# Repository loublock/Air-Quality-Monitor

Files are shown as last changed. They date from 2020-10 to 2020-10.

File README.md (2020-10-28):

# Air Quality Monitor

This project's topic is a device capable to measure the surrounding air quality dependent on CO2 and CO value as well as air temperature, pressure, and relative humidity. 
The idea is to monitor the air quality in order to give feedback on how "healthy" the air in your room really is. In times of Coronavirus, this can be used as an indicator to ventilate your office or living room in order to minimize the infection risk. A LED stripe signals you the time to ventilate the room and also when the CO2/CO concentration gets unhealthy.

## Table of Contents

1. Working principle
   1. Idea
   2. Sensors and actuators
   3. Code explanation
2. Adjustable parameters
3. Used hardware
4. Wiring
5. 3D printed housing
6. Assembly
7. Credits

## 1 Working principle
### 1.1 Idea
By measuring the gas concentration of CO2/CO the quality of the ambient air can be determined. Thinking of an office room for example, by having no other CO2 source than humans, the amount of CO2 in the air is relative to the number of people in the room and the time without ventilation. To minimize the risk of infection and maximize human performance, a small amount of CO2 is required. 

### 1.2 Sensors and actuators
The CO2/CO is measured by an MQ-135 gas sensor, returns the gas concentration in PPM (more in this repo: https://github.com/miguel5612/MQSensorsLib). This value depends on the temperature and the rel. humidity in the room. A BME280 sensor is used to get this information. Adding the temperature compensation to the MQSensorsLib according to formulas in this repo https://github.com/GeorgK/MQ135, we should get pretty accurate reading values. 

All the sensor values are shown on an I2C OLED display, switching between the two menus via a push button. If a critical value of CO2/CO in the room is reached, the indicator LEDs will blink red. They will scroll in orange when room ventilation is suggested. A gas concentration upper and lower limit is configured therefor.

### 1.3 Code explanation
In this section, I'll explain the most important functions in short. 

**loop()** is checking the gas limits, LED mode, and display mode. Pressing button one switches between the display modes, button two between the LED modes (gas warning and flashlight). The variables checked here get toggled in the button interrupt service routine (ISR).

**print_readings_display()** prints the regular three/four lines of reading values.

**print_alarm_value_display()** prints the gas reading value in big that exceeded it's upper limit.

**blink_LED()** blinking LEDs

**glow_LED()** LEDs on

**scroll_LED()** LEDs scrolling

**btn_press_ISR()** button ISR (debounced). Checks which button has been pressed and toggles the corresponding variable. (See more here: https://create.arduino.cc/projecthub/Svizel_pritula/10-buttons-using-1-interrupt-2bd1f8)

**init_mq135()** sets RL value according to define and reads out R0 from EEPROM.

**calibration_mq135()** calibrates the MQ135 R0 value if variable *mq135_cal_done* is set to false.

**get_mq135_readings()** reads sensor values, smoothes them and applies temperature/humidity compensation.

## 2 Adjustable parameters 

**Important: The MQ135 needs to be calibrated once! To do so change the variable *mq135_cal_done* on false and place it outside (fresh air). After heating (5 min) the calibration starts (30 sec). After that change the variable back to true, the calibrated R0 is written to EEPROM and is read out on device start.** 

- Resistor at pin B2 of your MQ135. (1k at most Chinese boards but it should one between 10k and 47k, 20k ideal.)

*#define RL 20* 

- Pre heating of MQ135 in milliseconds, 5 mins is recommended.

*#define HEATING_TIME 300000* 

- Your atmospheric CO2 value, if you know it exactly at your location.

*#define ATMOCO2 410* 

- Upper CO2 limit (when red blinking starts)

*#define CO2_MAX 2000* 

- Lower CO2 limit (when green glowing starts)
(Between upper and lower limit the LEDs scrolling in orange.)

*#define CO2_LOW 1000* 

- Upper CO limit (when red blinking starts)

*#define CO_MAX 70* 

- Lower CO limit (when green glowing starts)

*#define CO_LOW 40* 

You can change the pinout or anything else of course if you desire, but beware of side effects!

## 3 Used hardware 
- BME280 sensor board
- Oled I2C 128x32
- MQ-135 sensor board
- 2x push button
- WS2812 LED stripe 60 pixels/m
- Arduino Nano
- 20 mm round switch
- 6x M3x10 mm

## 4 Wiring 
*image coming soon*

**Arduino Nano:**

- **D7:** button 1
- **D6:** button 2 (or vise versa)
- **D2:** common button GND (same interrupt)
- **D5:** WS2812 LED stripe
- **A0:** MQ135
- **A4:** OLED + BME280 (I2C) SDA
- **A5:** OLED + BME280 (I2C) SCL

**BME280 (I2C):**

- **Vin:** +5V Arduino
- **GND:** GND Arduino
- **SCL:** A5 Arduino
- **SDA:** A4 Arduino

**Display (I2C):**

- **Vin:** +5V Arduino
- **GND:** GND Arduino
- **SCL:** A5 Arduino
- **SDA:** A4 Arduino

**MQ-135:**

- **Vin:** +5V Arduino
- **GND:** GND Arduino
- **A0:** A0 Arduino
- **D0:** Not connected

**Button 1:**

- **Vin:** D7 Arduino
- **GND:** D2 Arduino

**Button 2:**

- **Vin:** D6 Arduino
- **GND:** D2 Arduino

**LED stripe:**

- **Vin:** +5V Arduino
- **GND:** GND Arduino
- **Din:** D5 Arduino

## 5 3D printed housing
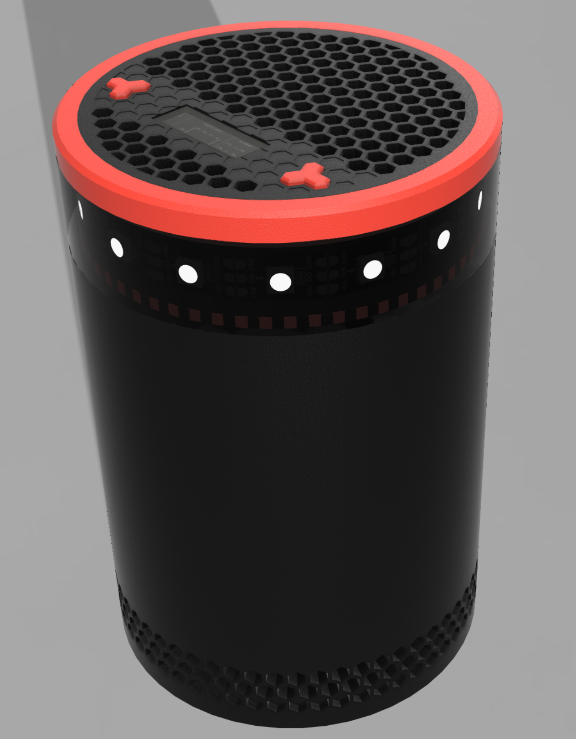
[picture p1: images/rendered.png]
rendered


Print all the files in the folder *3d_print* according to the table below. Please notice that you only need to print one lid, either the one with battery support or without. The one without battery is there to place your Arduino Nano in and connect it directly to USB power. The one with the battery support is able to hold up to four 18650 batteries as well as a charging board.

Part | Layer height | Color | Horizontal Expansion
---- | ------------ | ----- | --------------------
Top Grid | 0.2 mm | Black | -0.05 mm
Lower Housing | 0.2 mm | Black | 0
Button Bracket | 0.2 mm | Black | -0.05 mm
Sensor Bracket | 0.2 mm | Black | 0 
Button Left | 0.2 mm | Red | 0
Button Right | 0.2 mm | Red | 0
LED Mount | 0.2 mm | Red | -0.05 mm
Glass | 0.2 mm | Transparent | 0
Lid Battery | 0.2 mm | Black | 0 
Lid | 0.2 mm | Black | 0 

## 6 Assembly
Assemble all parts as shown in the picture and solder the cables concurrently. Screw the parts together with the M3's.

assembly

## 7 Credits

Thanks to **Matthias E.** for the design of the 3D-printed housing.

**MQ135 library:** Thanks to **Miguel A. Califa U.** (https://github.com/miguel5612/MQSensorsLib) for the general functions 
and **George K.** (https://github.com/GeorgK/MQ135) for the temperature compensation.

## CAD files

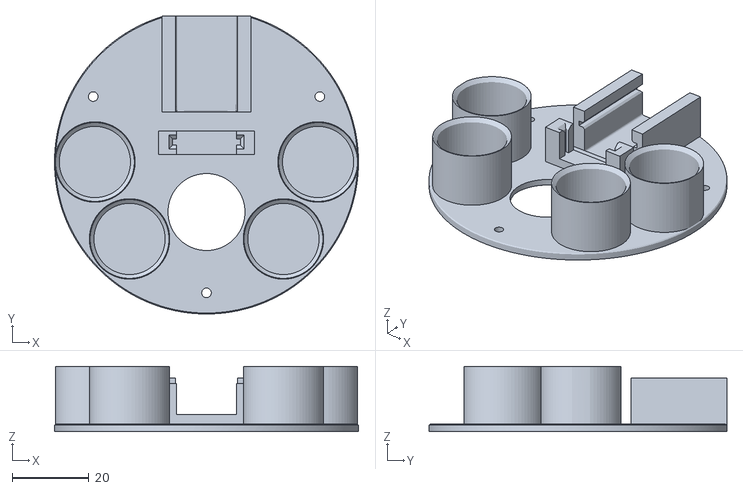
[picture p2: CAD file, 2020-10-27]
3d_print/black/lid_battery.stl
79.0 x 77.4 x 17.0

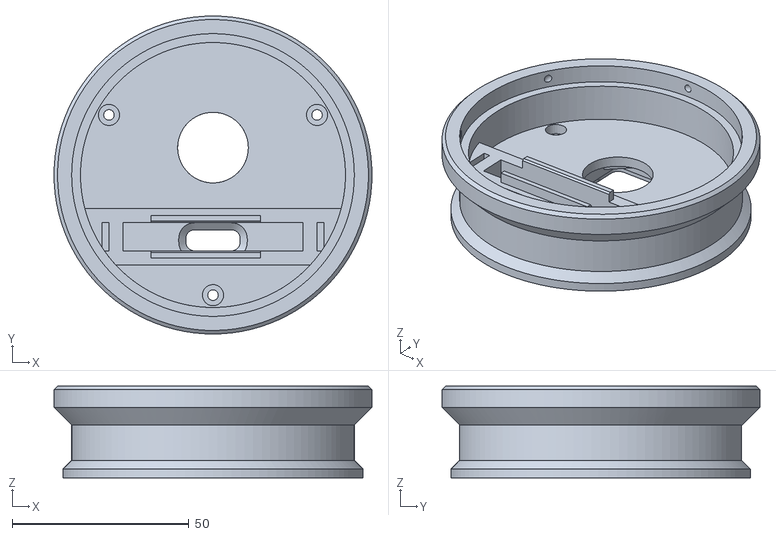
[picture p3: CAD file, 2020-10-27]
3d_print/red/led_mount.stl
90.0 x 90.0 x 26.0

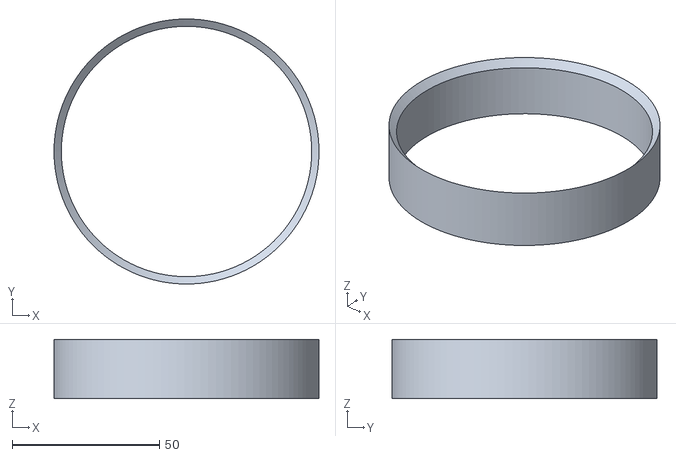
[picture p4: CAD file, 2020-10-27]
3d_print/transparent/glass.stl
90.0 x 90.0 x 20.1

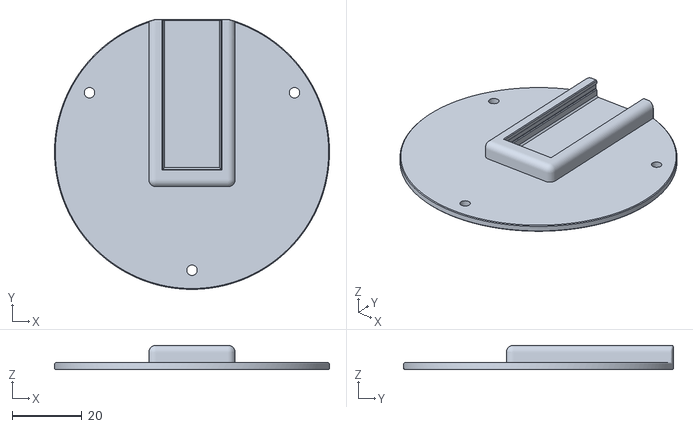
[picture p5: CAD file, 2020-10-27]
3d_print/black/lid.stl
79.0 x 77.5 x 7.00

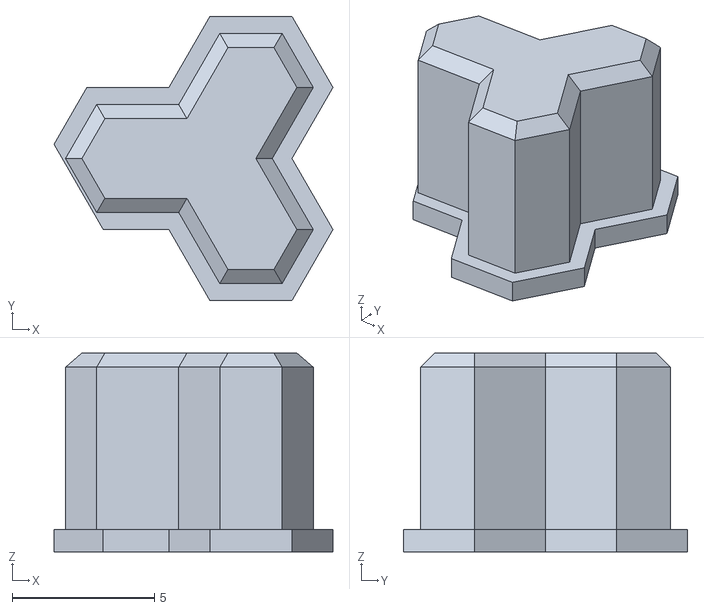
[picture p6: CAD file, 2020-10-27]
3d_print/red/button_left.stl
9.81 x 10.0 x 7.00

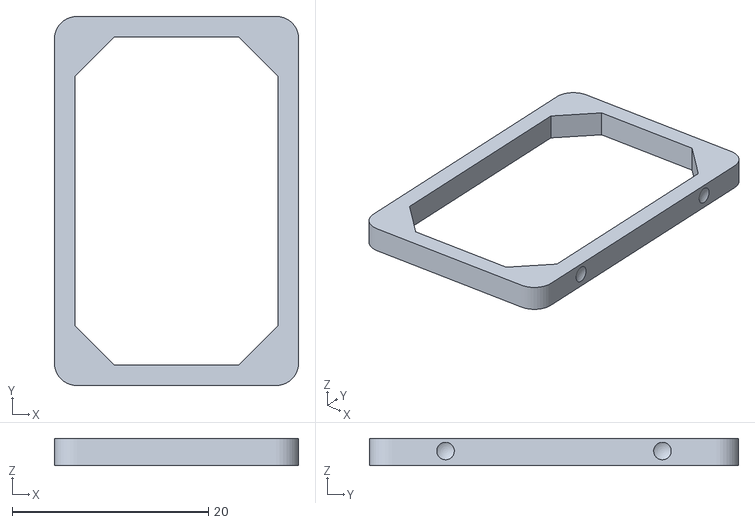
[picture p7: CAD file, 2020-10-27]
3d_print/black/sensor_bracket.stl
24.9 x 37.6 x 2.80

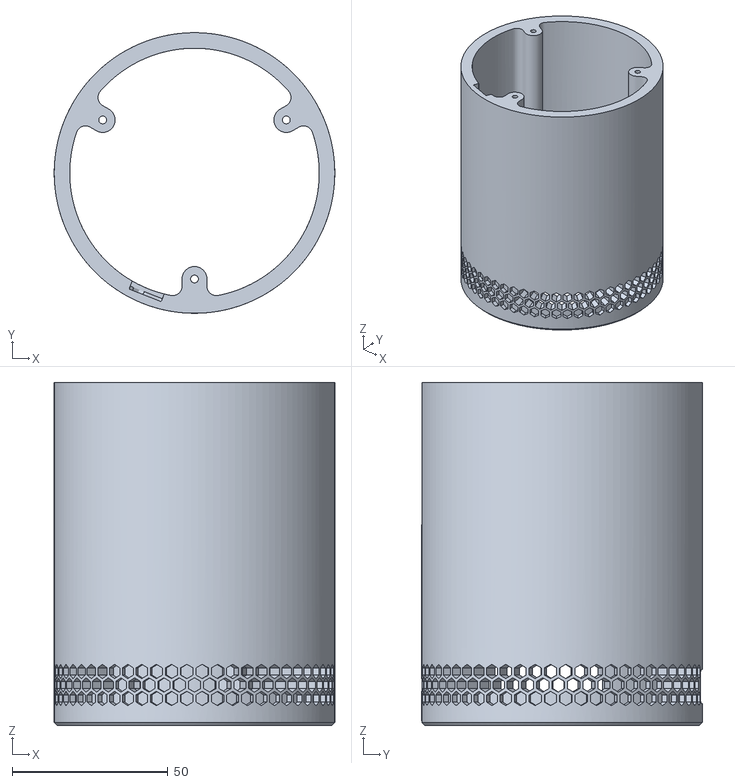
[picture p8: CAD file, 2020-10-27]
3d_print/black/lower_housing.stl
90.0 x 90.0 x 110.0

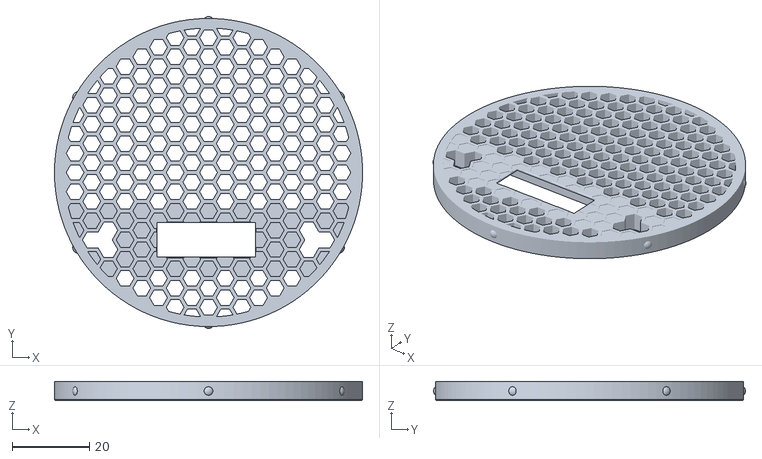
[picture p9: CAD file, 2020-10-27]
3d_print/black/top_grid.stl
80.0 x 81.0 x 5.00

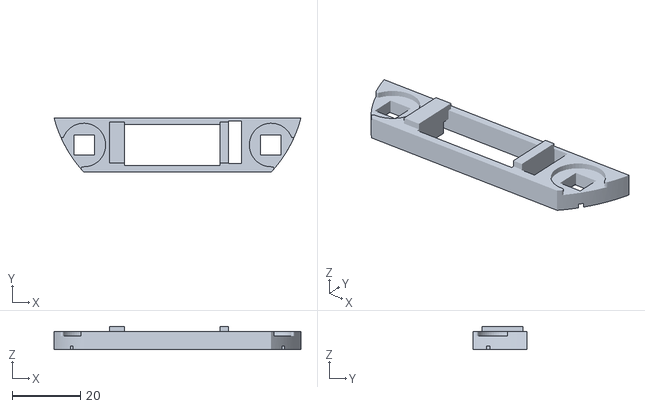
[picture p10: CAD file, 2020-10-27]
3d_print/black/button_bracket.stl
72.6 x 16.0 x 6.80

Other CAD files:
3d_print/red/button_right.stl

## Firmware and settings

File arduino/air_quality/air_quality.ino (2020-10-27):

// Created by Luis Garcia
// https://github.com/loublock 

/*
--------------- Quick Arduino Nano pinout ---------------
D7: button 1
D6: button 1 (or vise versa)
D2: common button GND (same interrupt)
D5: WS2812 LED stripe

A0: MQ135
A4: OLED + BME280 (I2C)
A4: OLED + BME280 (I2C)
*/

#include <SPI.h>
#include <Wire.h>
#include <Adafruit_BME280.h>
#include <Adafruit_GFX.h>
#include <Adafruit_SSD1306.h>
#include <Adafruit_NeoPixel.h>
#include "MQUnifiedsensor.h"
#include <EEPROM.h>

#define SCREEN_WIDTH 128 // OLED display width, in pixels
#define SCREEN_HEIGHT 32 // OLED display height, in pixels
// Declaration for an SSD1306 display connected to I2C (SDA, SCL pins)
#define OLED_RESET     -1 // Reset pin # (or -1 if sharing Arduino reset pin)

#define LED_PIN 5 // LED stripe on D5
#define NUM_LEDS 15 // amount of WS2812 LEDs on the stripe

// useful LED defines
#define FAST 200
#define MEDIUM 500
#define SLOW 1000

#define PIN_BTN_0 7 // button 1 on D7
#define PIN_BTN_1 6 // button 2 on D6
#define COMMON_BTN_PIN 2 // buttons GND on D2 (interrupt)

Adafruit_BME280 bme;

// MQ135 defines as seen in the examples of Miguel A. Califa U.
#define SEALEVELPRESSURE_HPA (1013.25)
#define RatioMQ135CleanAir 3.6

#define TYPE "MQ-135"
#define BOARD "Arduino Nano"
#define MQ_PIN A0 // MQ135 on A0
#define ADC_BIT_RES 10
#define VOLTAGE_RES 5
// Resistor Load on ground pin of MQ135
#define RL 20

// heating time in ms
#define HEATING_TIME 300000 //~ 5 min

// temperature and rel humidity correction according to Georg Krocker
#define CORA 0.00035
#define CORB 0.02718
#define CORC 1.39538
#define CORD 0.0018

// approx. atmospheric CO2 in ppm measured at Mauna Loa Observatory, Hawaii (NOAA)
// oct 2020
#define ATMOCO2 410

// gas limits - edit if neccessary
// in theory triggering on one gas should be fine bc the curves are related
#define CO2_MAX 2000
#define CO2_LOW 1000
#define CO_MAX 70
#define CO_LOW 40

// decl & init of sensor values
float humidity = 0.0;
float temperature = 0.0;
float pressure = 0.0;
float altitude = 0.0;
float co2 = 0.0;
float co = 0.0;
float nh4 = 0.0;
// float toluol = 0.0;

// scrolling index
unsigned int train_idx = 0;
unsigned int rainbow_count = 0;
//r0 of mq135
int calcR0 = 0; 

// set this to false to calibrate the MQ 135
bool mq135_cal_done = true;

Adafruit_SSD1306 display(SCREEN_WIDTH, SCREEN_HEIGHT, &Wire, OLED_RESET);
Adafruit_NeoPixel pixels = Adafruit_NeoPixel(NUM_LEDS, LED_PIN, NEO_GRB + NEO_KHZ800);
MQUnifiedsensor MQ135(BOARD, VOLTAGE_RES, ADC_BIT_RES, MQ_PIN, TYPE);

// init button state
bool btn0_state = HIGH;
bool btn1_state = HIGH;

// connect interrupt pins with routines
unsigned long last_fire = 0;

// ----triggers to set in ISR----
// 0: hum/temp/press 1: CO2/CO/NH4
bool display_mode = 0;
// 0: gas conc. color 1: lamp (white 255)
bool led_mode = 0;

// mq135 pre heating variables
bool heating = true;
float timer_heat = 0;

// smoothing the reading values
unsigned int n_smooth = 0;
const int smooth_limit = 10;
float co2_buffer[smooth_limit];
float co_buffer[smooth_limit];
float nh4_buffer[smooth_limit];
// float toluol_buffer[smooth_limit];




void setup() 
{
  Serial.begin(9600);

  configure_common();
  attachInterrupt(0, btn_press_ISR, FALLING);

  // SSD1306_SWITCHCAPVCC = generate display voltage from 3.3V internally
  if(!display.begin(SSD1306_SWITCHCAPVCC, 0x3C)) 
  { 
    // Serial.println(F("SSD1306 allocation failed"));
    for(;;); // Don't proceed, loop forever
  }

  init_timer();
  init_mq135();

  // oled init
  display.setRotation(2);
  display.setTextSize(1);      
  display.setTextColor(WHITE); 
  display.setCursor(0, 0);     
  display.cp437(true);         // Use full 256 char 'Code Page 437' font

  pixels.begin();

  // start BME sensor
  if (!bme.begin(0x76)) 
  {
    // Serial.println("Could not find a valid BME280 sensor, check wiring!");
    while (1);
  }

  // Clear the buffer
  display.clearDisplay();
  display.display();

  // setting up parameters
  display.setTextSize(2);
  display.setTextColor(WHITE);
  display.setCursor(0, 0);
  
  // Display static welcome text
  // \201 - ü \204 - ä \224 - ö \253 - ½
  display.println(F("Luft"));
  display.println(F("Qualit\204t"));
  display.display();

  delay(2000);

  display.clearDisplay();
  display.display();
}


void loop() 
{
  humidity = bme.readHumidity();
  temperature = bme.readTemperature(); 
  pressure = bme.readPressure() / 100.0F;
  altitude = bme.readAltitude(SEALEVELPRESSURE_HPA);

  // gets only executed when mq135_cal_done is initialized with false
  calibration_mq135();
  // get mq135 sensor values
  get_mq135_readings();

  // reset display or the display writes the new readings over the old ones
  display.display();
  display.clearDisplay();

  // wait for finishing heating
  if (timer_heat >= HEATING_TIME)
  {
    timer_heat = 0;
    heating = false;
//    Serial.println(F("Aufheizen abgeschlossen!"));
//    Serial.println(F("MQ135 betriebsbereit!"));
  }

  if (led_mode)
  {
    print_regular_readings();
    glow_LED('white', 255);
  }
  else if (!heating)
  {
    // co2: green: <=1000, orange: 2000>val>1500 red: >=2000
    // co: green: <=50, orange: 70>val>50 red: >=70
    if (co2 >= CO2_MAX || co >= CO_MAX)
    {
      // tehre's a bug: if you put the predefines color into the LED functions, the color is wrong.
      // Also if you put the dec/hex value as parameter. Only direct color set is working, so strings are given.
      blink_LED('red', FAST, 255);
      if (co2 >= CO2_MAX)
      {
        print_alarm_value_display("CO2: ", co2, "PPM", false, 0);
      }
      else
      {
        print_alarm_value_display("CO: ", co, "PPM", false, 0);
      }
    }
    else if (co2 <= CO2_LOW && co <= CO_LOW)
    {
      print_regular_readings();
      glow_LED('green', 15);
    }
    else
    {
      print_regular_readings();
      scroll_LED('orange', FAST, 5, 100);
    }
  }
  else
  {
    print_regular_readings();
    // rainbow_scroll_LED(); 
    scroll_LED('blue', MEDIUM, 5, 50);
  }
  

  // delay(10);
}


//----------------------OLED write routine---------------------------------------------------
void print_readings_display(float value, int line, String label, int offset, String unit, 
                            int textsize, bool is_spec_unit, int special_unit, bool blinking)
{
  display.setTextSize(textsize);
  display.setCursor(0, line);
  display.print(label);
  display.setCursor(offset, line);
  display.print(value);
  display.print(" ");

  if (is_spec_unit)
  {
    display.cp437(true);
    display.write(special_unit);
  }
 
  display.print(unit);
}


void print_alarm_value_display(String val_label, float alarm_value, String unit, 
                               bool is_spec_unit, int special_unit)
{
  // first print what value is alarming
  display.setTextSize(1);
  display.setCursor(0, 0);
  display.print(val_label);

  // then the value in big
  display.setTextSize(2);
  display.setCursor(0, 10);
  display.print(alarm_value);
  display.print(" ");

    if (is_spec_unit)
  {
    display.cp437(true);
    display.write(special_unit);
  }
 
  display.print(unit);
}


void print_regular_readings()
{
  if (!display_mode)
  {
    print_readings_display(co2, 0, "CO2: ", 40, "PPM", 1, false, 0, false);
    print_readings_display(co, 10, "CO: ", 40, "PPM", 1, false, 0, false);
    print_readings_display(nh4, 20, "NH4: ", 40, "PPM", 1, false, 0, false);
    // print_readings_display(toluol, 23, "Toluol: ", 40, "PPM", 1, false, 0, false);
    // print_readings_display(calcR0, 20, "R0: ", 40, "", 1, false, 0, false);
  }
  else
  {
    print_readings_display(temperature, 0, "Temperatur: ", 75, "C", 1, true, 167, false);
    print_readings_display(humidity, 7, "Feuchte: ", 75, "%", 1, false, 0, false);
    print_readings_display(pressure, 15, "Druck: ", 60, "hPa", 1, false, 0, false);
    print_readings_display(altitude, 23, "H\224he: ", 60, "m", 1, false, 0, false);
  }
}


//--------------------------LED stripe routines---------------------------------------------
void blink_LED(int color, int speed, int brightness)
// lets the LEDs blink in a specific color, brightness and speed
{
  pixels.setBrightness(brightness);
  pixels.show();

  // if off turn on
  if (pixels.getPixelColor(0) == pixels.Color(0,0,0))
  {
    for (int n=0; n<NUM_LEDS; n++)
    {
      // turn on the train pixels
      if (color == 'red')
        pixels.setPixelColor(n, pixels.Color(255,0,0));
      else if (color == 'green')
        pixels.setPixelColor(n, pixels.Color(0,255,0));
      else if (color == 'blue')
        pixels.setPixelColor(n, pixels.Color(0,0,255));
      else if (color == 'orange')
        pixels.setPixelColor(n, pixels.Color(255,165,0));
      else
        pixels.setPixelColor(n, pixels.Color(255,255,255));
    }
    
    pixels.show();
    }
  // else turn off
  else
  {
    pixels.clear();
    pixels.show();
  }
  
  delay(speed);
}


void glow_LED(int color, int brightness)
// just turn on the LEDs at specific color and brightness
{
  pixels.setBrightness(brightness);
  pixels.show();

  for (int n=0; n<NUM_LEDS; n++)
  {
    // turn on the train pixels
    if (color == 'red')
      pixels.setPixelColor(n, pixels.Color(255,0,0));
    else if (color == 'green')
      pixels.setPixelColor(n, pixels.Color(0,255,0));
    else if (color == 'blue')
      pixels.setPixelColor(n, pixels.Color(0,0,255));
    else if (color == 'orange')
      pixels.setPixelColor(n, pixels.Color(255,165,0));
    else
      pixels.setPixelColor(n, pixels.Color(255,255,255));
  }

  pixels.show();
}


void scroll_LED(int color, int speed, int length, int brightness)
// this function lets a specific amount of LEDs travel around the stripe
// at a specific speed
{
  int diff = 0;
  pixels.setBrightness(brightness);
  pixels.show();

  // create a - let's call it a train, a train of LED light pixels
  // it has a length of pixels and a speed with which it moves on the LED stripe
  for (int t=train_idx; t<train_idx+length; t++)
  {
    // turn on the train pixels
    if (color == 'red')
      pixels.setPixelColor(t, pixels.Color(255,0,0));
    else if (color == 'green')
      pixels.setPixelColor(t, pixels.Color(0,255,0));
    else if (color == 'blue')
      pixels.setPixelColor(t, pixels.Color(0,0,255));
    else if (color == 'orange')
      pixels.setPixelColor(t, pixels.Color(255,165,0));
    else
      pixels.setPixelColor(t, pixels.Color(255,255,255));
    
  }
  // make them gloooow
  pixels.show();

  // blinking speed is too slow for here
  delay(speed/10);

  pixels.clear();
  // pixels.show();  

  train_idx++;
  if ((train_idx + length) > NUM_LEDS)
  {
    train_idx = 0;
  }
}


void rainbow_scroll_LED()
{
  if (rainbow_count >= 65536)
  {
    rainbow_count = 0;
  }
  else
  {
    for(int i=0; i<NUM_LEDS; i++) 
    {
      int pixel_hue = rainbow_count + (i * 65536L / NUM_LEDS);
      scroll_LED(pixels.gamma32(pixels.ColorHSV(pixel_hue)), MEDIUM, 5, 150);
    }
    rainbow_count++;
  }
  
}


// ----------------------button interrupt service routine-------------------------------------------------------
// you can use one ISR for more than one button, when you connect all buttons GND
// to one digital pin and set that to LOW --> COMMON_BTN_PIN
// when you connect the pin with the ISR you dont use the buttons digital pin, but your common pin
// finally you check in the ISR which button got pressed
void btn_press_ISR()
{
  // debounce the button, bc this is not Nicki Minaj
  if (millis() - last_fire < 200) 
  { 
    return;
  }
  last_fire = millis();

  configure_distinct();

  // get the button states - which one got pressed actully
  btn0_state = digitalRead(PIN_BTN_0);
  btn1_state = digitalRead(PIN_BTN_1);

  if (btn0_state == LOW)
  {
    display_mode = !display_mode;
  }
  else if (btn1_state == LOW)
  {
    led_mode = !led_mode;
  }

  configure_common();
}


// this magic is written by this guy 
// https://create.arduino.cc/projecthub/Svizel_pritula/10-buttons-using-1-interrupt-2bd1f8
void configure_common()
{
  pinMode(COMMON_BTN_PIN, INPUT_PULLUP);

  pinMode(PIN_BTN_0, OUTPUT);
  pinMode(PIN_BTN_1, OUTPUT);
  digitalWrite(PIN_BTN_0, LOW);
  digitalWrite(PIN_BTN_1, LOW);
}


void configure_distinct()
{
  pinMode(COMMON_BTN_PIN, OUTPUT);
  digitalWrite(COMMON_BTN_PIN, LOW);

  pinMode(PIN_BTN_0, INPUT_PULLUP);
  pinMode(PIN_BTN_1, INPUT_PULLUP);
}


// -----------------others------------------------------------
void init_mq135()
{
  //Set math model to calculate the PPM concentration and the value of constants
  MQ135.init();
  // set your RL resistor (china default: 1k, replace with one between 10k and 47k)
  // the greater the resistance on RL, the more sensitive the sensor becomes
  MQ135.setRL(RL); //20k
  MQ135.setRegressionMethod(1); //_PPM =  a*ratio^b

  calcR0 = EEPROM.read(0x00);
  // Serial.print("R0 aus EEPROM: ");
//  Serial.println(calcR0);
  MQ135.setR0(calcR0); 

  // Serial.println("3 Minuten heizen! Bitte warten...");
}


void calibration_mq135()
// calibration is done in pre heated sensor state! (replace 1k Ohm resistor on GND with a 20k)
{
  if (mq135_cal_done)
  {
    return;
  }

  if (!heating)
  {
    // Serial.println("Kalibrierung, bitte warten! ");
    int calcR0 = 0;

    for(int i=0; i<15; i++)
    {
      delay(2000);
      // get temp and hum for compensation
      humidity = bme.readHumidity();
      temperature = bme.readTemperature();
      // calculate correction factor
      float cf = CORA * temperature * temperature - CORB * temperature + CORC - (humidity - 33.) * CORD;

      MQ135.update(); // Update data, the arduino will be read the voltage on the analog pin
      //Serial.println(MQ135.calibrate(RatioMQ135CleanAir));
      calcR0 += MQ135.calibrate(RatioMQ135CleanAir, cf);
    }

    // Serial.println("Berechne Widerstandswert:");
    calcR0 = calcR0/15;
    // Serial.println(calcR0);
    MQ135.setR0(calcR0);
    //Kalibrierwert in Festspeicher schreiben!
    EEPROM.write(0, calcR0);
    // Serial.println("Kalibrierung beendet!");
    mq135_cal_done = true;
  }
}


void get_mq135_readings()
{
  // https://github.com/miguel5612/MQSensorsLib

  /*
    Exponential regression:
  GAS      | a      | b
  CO       | 605.18 | -3.937  
  Alcohol  | 77.255 | -3.18 
  CO2      | 110.47 | -2.862
  Tolueno  | 44.947 | -3.445
  NH4      | 102.2  | -2.473
  Acetona  | 34.668 | -3.369
  */
  // smooth the readings over n values
  if (n_smooth >= smooth_limit)
  {
    co = 0.0;
    co2 = 0.0;
    nh4 = 0.0;
    
    for (int n=0; n<smooth_limit; n++)
    {
      co += co_buffer[n];
      co2 += co2_buffer[n];
      nh4 += nh4_buffer[n];
      // toluol += toluol_buffer[n];
    }
    co /= smooth_limit;
    co2 /= smooth_limit;
    nh4 /= smooth_limit;
    // toluol /= smooth_limit;

    n_smooth = 0;
  } 

  // correction factor dependant of temperature and humidity 
  // (credits to George K. --> https://github.com/GeorgK/MQ135)
  float cf = CORA * temperature * temperature - CORB * temperature + CORC - (humidity - 33.) * CORD;

  MQ135.update(); // Update data, the arduino will be read the voltage on the analog pin

  MQ135.setA(605.18); MQ135.setB(-3.937); // Configurate the ecuation values to get CO concentration
  co_buffer[n_smooth] = MQ135.readSensor(cf); // Sensor will read PPM concentration using the model and a and b values setted before or in the setup

  MQ135.setA(110.47); MQ135.setB(-2.862); // Configurate the ecuation values to get CO2 concentration
  co2_buffer[n_smooth] = MQ135.readSensor(cf) * 100 + ATMOCO2; // Sensor will read PPM concentration using the model and a and b values setted before or in the setup
  // when the library is calibrated it assumes the current state of the
  // air as 0 PPM, and it is considered today that the CO2 present in the atmosphere is around 400 PPM.

  // MQ135.setA(44.947); MQ135.setB(-3.445); // Configurate the ecuation values to get Tolueno concentration
  // toluol_buffer[n_smooth] = MQ135.readSensor(cf); // Sensor will read PPM concentration using the model and a and b values setted before or in the setup

  MQ135.setA(102.2); MQ135.setB(-2.473); // Configurate the ecuation values to get NH4 concentration
  nh4_buffer[n_smooth] = MQ135.readSensor(cf); // Sensor will read PPM concentration using the model and a and b values setted before or in the setup

  n_smooth++;
}


void init_timer()
{
  //use timer register 1, because regist 0 interfers with our button interrupts
  //timer for heating MQ135 time: 1kHz 
  TCCR2A=(1<<WGM21);    //Set CTC mode   
  OCR2A=249; //Value for ORC0A for 1ms
  
  TIMSK2|=(1<<OCIE2A);   //Set the interrupt request
  
  TCCR2B|=(1<<CS22);    //Set prescaler to 64

  sei(); //Enable interrupt
}


//interrupt request t1
ISR(TIMER2_COMPA_vect)
{   
  if (heating)
  {
    timer_heat++;
  }
}

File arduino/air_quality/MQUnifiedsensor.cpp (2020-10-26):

#include "MQUnifiedsensor.h"

MQUnifiedsensor::MQUnifiedsensor(String Placa, float Voltage_Resolution, int ADC_Bit_Resolution, int pin, String type) {
  this->_pin = pin;
  Placa.toCharArray(this->_placa, 20);
  type.toCharArray(this->_type, 6);
  //this->_type = type; //MQ-2, MQ-3 ... MQ-309A
  //this->_placa = Placa;
  this-> _VOLT_RESOLUTION = Voltage_Resolution;
  this-> _ADC_Bit_Resolution = ADC_Bit_Resolution;
}
void MQUnifiedsensor::init()
{
  pinMode(_pin, INPUT);
}
void MQUnifiedsensor::setA(float a) {
  this->_a = a;
}
void MQUnifiedsensor::setB(float b) {
  this->_b = b;
}
void MQUnifiedsensor::setR0(float R0) {
  this->_R0 = R0;
}
void MQUnifiedsensor::setRL(float RL) {
  this->_RL = RL;
}
void MQUnifiedsensor::setADC(int value)
{
  this-> _sensor_volt = (value) * _VOLT_RESOLUTION / ((pow(2, _ADC_Bit_Resolution)) - 1); 
  this-> _adc =  value;
}
void MQUnifiedsensor::setVoltResolution(float voltage_resolution)
{
  _VOLT_RESOLUTION = voltage_resolution;
}
void MQUnifiedsensor::setRegressionMethod(int regressionMethod)
{
  //this->_regressionMethod = regressionMethod;
  this->_regressionMethod = regressionMethod;
}
float MQUnifiedsensor::getR0() {
  return _R0;
}
float MQUnifiedsensor::getRL() {
  return _RL;
}
float MQUnifiedsensor::getVoltResolution()
{
  return _VOLT_RESOLUTION;
}
String MQUnifiedsensor::getRegressionMethod()
{
  if(_regressionMethod == 1) return "Exponential";
  else return "Linear";
}
float MQUnifiedsensor::getA() {
  return _a;
}
float MQUnifiedsensor::getB() {
  return _b;
}
void MQUnifiedsensor::serialDebug(bool onSetup)
{
  if(onSetup)
  {
    Serial.println();
    Serial.println("************************************************************************************************************************************************");
    Serial.println("MQ sensor reading library for arduino");

    Serial.println("Note: remember that all the parameters below can be modified during the program execution with the methods:");
    Serial.println("setR0, setRL, setA, setB where you will have to send as parameter the new value, example: mySensor.setR0(20); //R0 = 20KΩ");

    Serial.println("Authors: Miguel A. Califa U - Yersson R. Carrillo A - Ghiordy F. Contreras C");
    Serial.println("Contributors: Andres A. Martinez - Juan A. Rodríguez - Mario A. Rodríguez O ");

    Serial.print("Sensor: "); Serial.println(_type);
    Serial.print("Supply voltage: "); Serial.print(_VOLT_RESOLUTION); Serial.println(" VDC");
    Serial.print("ADC Resolution: "); Serial.print(_ADC_Bit_Resolution); Serial.println(" Bits");
    Serial.print("R0: "); Serial.print(_R0); Serial.println(" KΩ");
    Serial.print("RL: "); Serial.print(_RL); Serial.println(" KΩ");

    Serial.print("Model: "); if(_regressionMethod == 1) Serial.println("Exponential"); else Serial.println("Linear");
    Serial.print(_type); Serial.print(" -> a: "); Serial.print(_a); Serial.print(" | b: "); Serial.println(_b);

    Serial.print("Development board: "); Serial.println(_placa);
  }
  else 
  {
    if(!_firstFlag)
    {
      Serial.print("| ********************************************************************"); Serial.print(_type); Serial.println("*********************************************************************|");
      Serial.println("|ADC_In | Equation_V_ADC | Voltage_ADC |        Equation_RS        | Resistance_RS  |    EQ_Ratio  | Ratio (RS/R0) | Equation_PPM |     PPM    |");
      _firstFlag = true;  //Headers are printed
    }
    else
    {
      Serial.print("|"); Serial.print(_adc);  Serial.print("| v = ADC*"); Serial.print(_VOLT_RESOLUTION); Serial.print("/"); Serial.print((pow(2, _ADC_Bit_Resolution)) - 1); Serial.print("  |    "); Serial.print(_sensor_volt);
      Serial.print("     | RS = ((" ); Serial.print(_VOLT_RESOLUTION ); Serial.print("*RL)/Voltage) - RL|      "); Serial.print(_RS_Calc); Serial.print("     | Ratio = RS/R0|    ");
      Serial.print(_ratio);  Serial.print( "       |   ");
      if(_regressionMethod == 1) Serial.print("ratio*a + b");
      else Serial.print("pow(10, (log10(ratio)-b)/a)");
      Serial.print("  |   "); Serial.print(_PPM); Serial.println("  |");
    }
  }
}
void MQUnifiedsensor::update()
{
  _sensor_volt = this->getVoltage();
}
float MQUnifiedsensor::validateEcuation(float ratioInput)
{
  //Serial.print("Ratio input: "); Serial.println(ratioInput);
  //Serial.print("a: "); Serial.println(_a);
  //Serial.print("b: "); Serial.println(_b);
  //Usage of this function: Unit test on ALgorithmTester example;
  if(_regressionMethod == 1) _PPM= _a*pow(ratioInput, _b);
  else 
  {
      // https://jayconsystems.com/blog/understanding-a-gas-sensor
      double ppm_log = (log10(ratioInput)-_b)/_a; //Get ppm value in linear scale according to the the ratio value  
      _PPM = pow(10, ppm_log); //Convert ppm value to log scale  
  }
  //Serial.println("Regression Method: "); Serial.println(_regressionMethod);
  //Serial.println("Result: "); Serial.println(_PPM);
  return _PPM;  
}
float MQUnifiedsensor::readSensor(float cf)
{
  //More explained in: https://jayconsystems.com/blog/understanding-a-gas-sensor
  _RS_Calc = ((_VOLT_RESOLUTION*_RL)/_sensor_volt)-_RL; //Get value of RS in a gas
  if(_RS_Calc < 0)  _RS_Calc = 0; //No negative values accepted.
  _ratio = (_RS_Calc/cf) / this->_R0;   // Get ratio RS_gas/RS_air
  if(_ratio <= 0)  _ratio = 0; //No negative values accepted or upper datasheet recomendation.
  if(_regressionMethod == 1) _PPM= _a*pow(_ratio, _b); // <- Source excel analisis https://github.com/miguel5612/MQSensorsLib_Docs/tree/master/Internal_design_documents
  else 
  {
    // https://jayconsystems.com/blog/understanding-a-gas-sensor <- Source of linear ecuation
    double ppm_log = (log10(_ratio)-_b)/_a; //Get ppm value in linear scale according to the the ratio value  
    _PPM = pow(10, ppm_log); //Convert ppm value to log scale  
  }
  if(_PPM < 0)  _PPM = 0; //No negative values accepted or upper datasheet recomendation.
  //if(_PPM > 10000) _PPM = 99999999; //No negative values accepted or upper datasheet recomendation.
  return _PPM;
}
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

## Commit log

2020-10-27 changed pre heat time to 5min, added image of device, added 3d printing files
    [button_bracket.stl, button_left.stl, button_right.stl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]
2020-10-27 added missing lids and assembly instructions
    [lid.stl, lid_battery.stl]
